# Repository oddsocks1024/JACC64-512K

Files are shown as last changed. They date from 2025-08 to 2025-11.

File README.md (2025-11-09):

# JACC64-512K
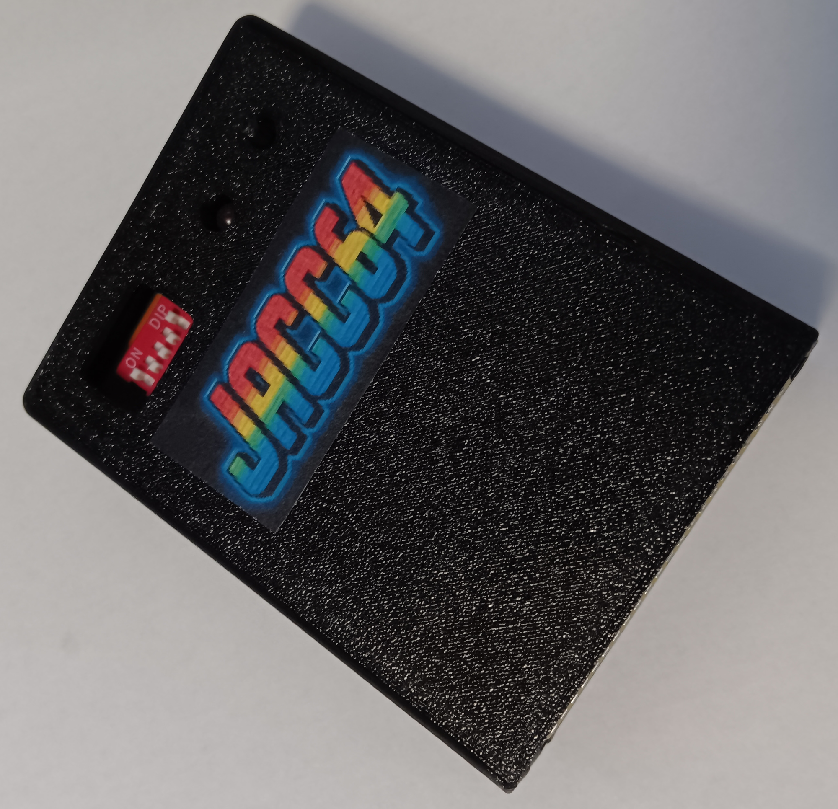
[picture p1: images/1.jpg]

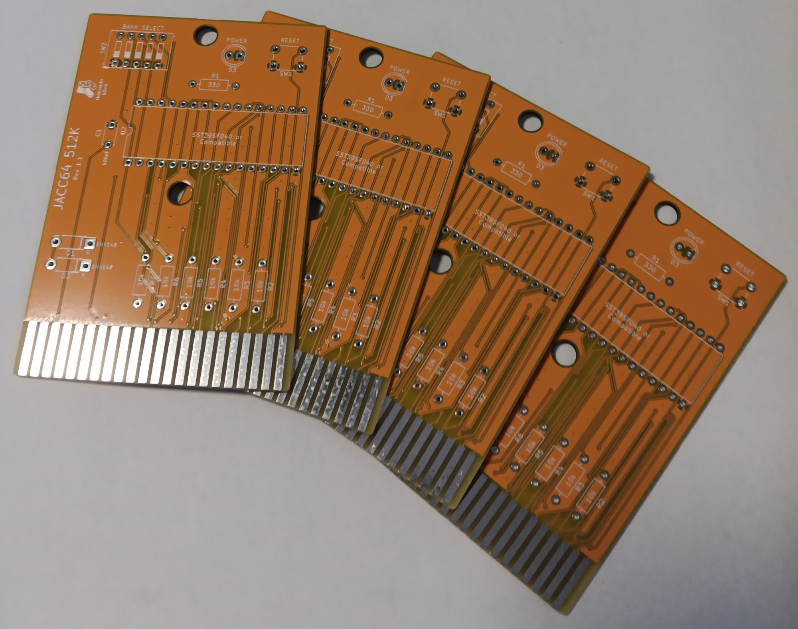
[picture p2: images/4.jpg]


## Description
JACC64-512K: Just Another Commodore Cartridge.

A cartridge for the Commodore 64 that holds 32 selectable 16K ROM images

**Additional Features**
* Power LED
* Reset Switch

## Bill of Materials

| Qty | Component |
|:---:|---|
| 1 | 5mm LED |
| 1 | 6mm Tactile Push Button |
| 1 | 330Ω Axial Resistor - ¼ watt (LED) |
| 6 | 10KΩ Axial Resistors - ¼ watt |
| 2 | 1N4148 Diodes |
| 1 | 100nF Ceramic Capacitor |
| 1 | 5-pole DIP Switch |
| 1 | SST39SF040 EEPROM (or compatible) |

* IC sockets optional
* The LED resistor is nominally 330Ω but anything up to 1K is fine
* You will need to join 32 x 16K ROM images together into a single image before burning to the EEPROM
* Smaller EEPROMs could be used, but will obviously hold fewer images and the DIP switch should be set accordingly

## 3D Printable Case
A 3D printable case specifically designed for this PCB is also available. STLs are included in this repo and there is also a [Thingiverse Page](https://www.thingiverse.com/thing:7089362)

* Designed to use screws as they produce a much nicer, more robust case
* 2 x 3.5mm self-tapping screws to attach the shells. Max length about 15mm

## Support Me
* [My Projects](https://projects.amiga-hardware.com) - Donate on this page
* [Order the JACC64-512K PCB](https://www.pcbway.com/project/shareproject/JACC64_512K_32_Game_C64_Cartridge_42f2de5b.html)
* [Order the JACC64-512K Case](https://www.pcbway.com/project/shareproject/JACC64_512K_C64_Cartridge_Case_49b9f140.html)

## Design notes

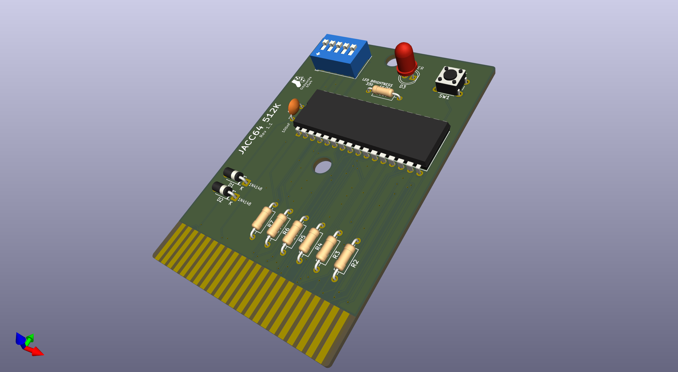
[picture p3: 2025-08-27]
images/JACC64-512K.png

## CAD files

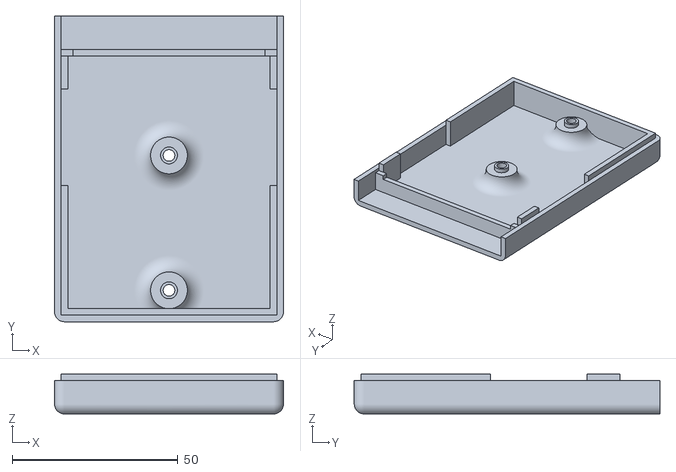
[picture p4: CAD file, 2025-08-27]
STL/JACC64-512K-Case-Bottom.stl
69.0 x 92.1 x 12.0

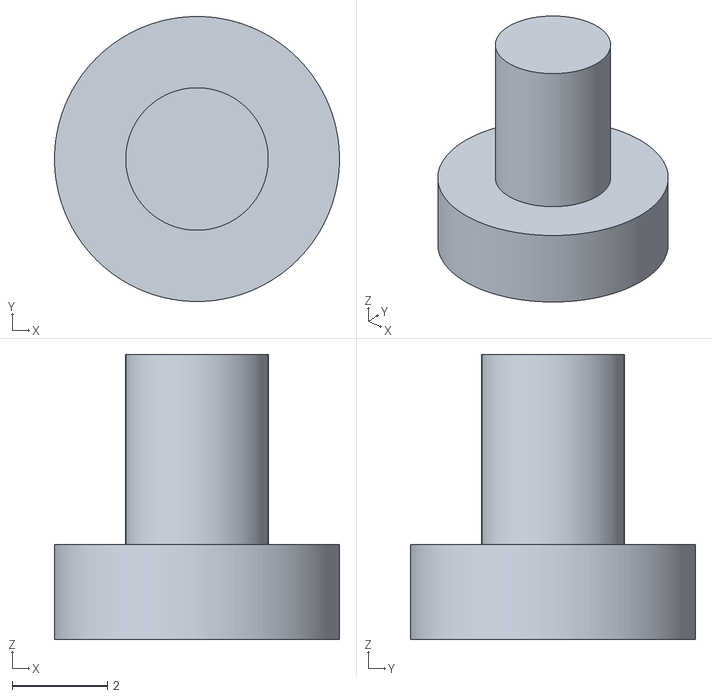
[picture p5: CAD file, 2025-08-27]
STL/JACC64-512K-Reset-Pin.stl
6.00 x 6.00 x 6.00

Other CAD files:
STL/JACC64-512K-Case-Top.stl

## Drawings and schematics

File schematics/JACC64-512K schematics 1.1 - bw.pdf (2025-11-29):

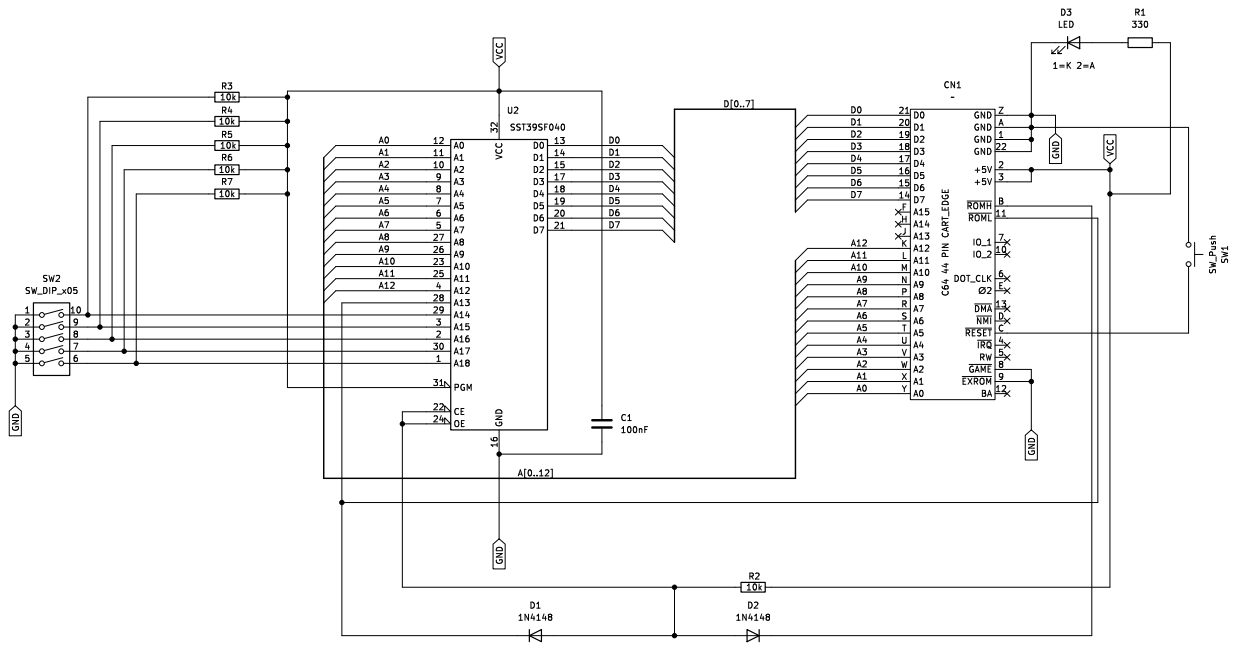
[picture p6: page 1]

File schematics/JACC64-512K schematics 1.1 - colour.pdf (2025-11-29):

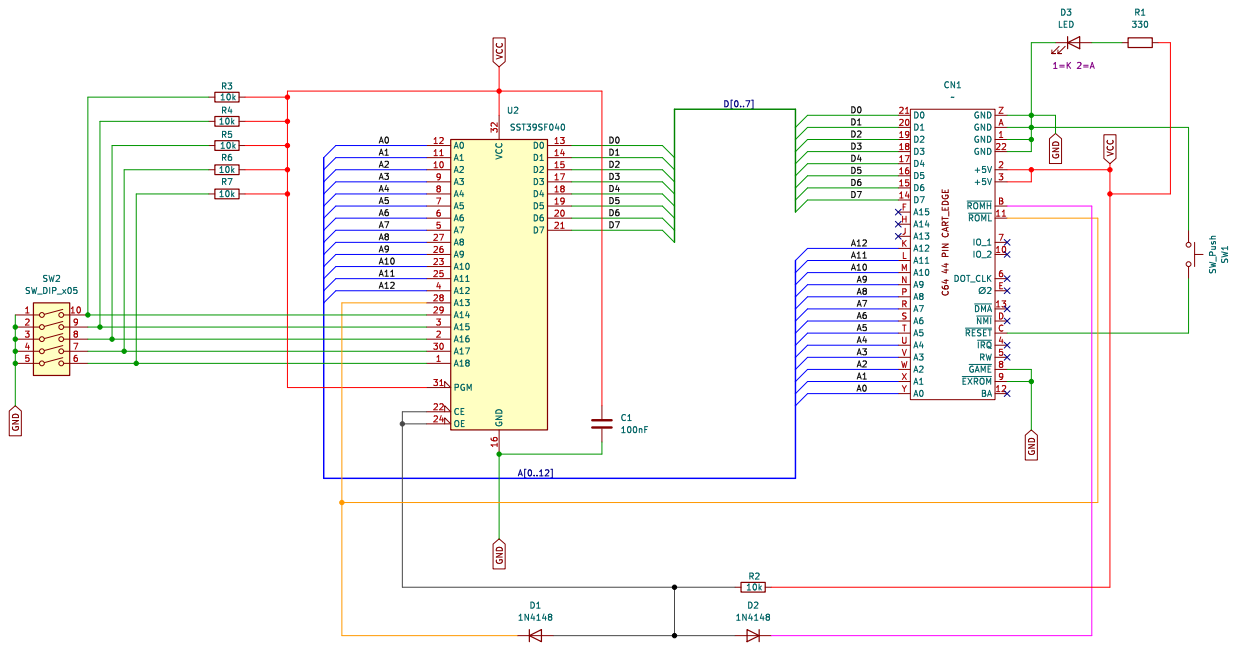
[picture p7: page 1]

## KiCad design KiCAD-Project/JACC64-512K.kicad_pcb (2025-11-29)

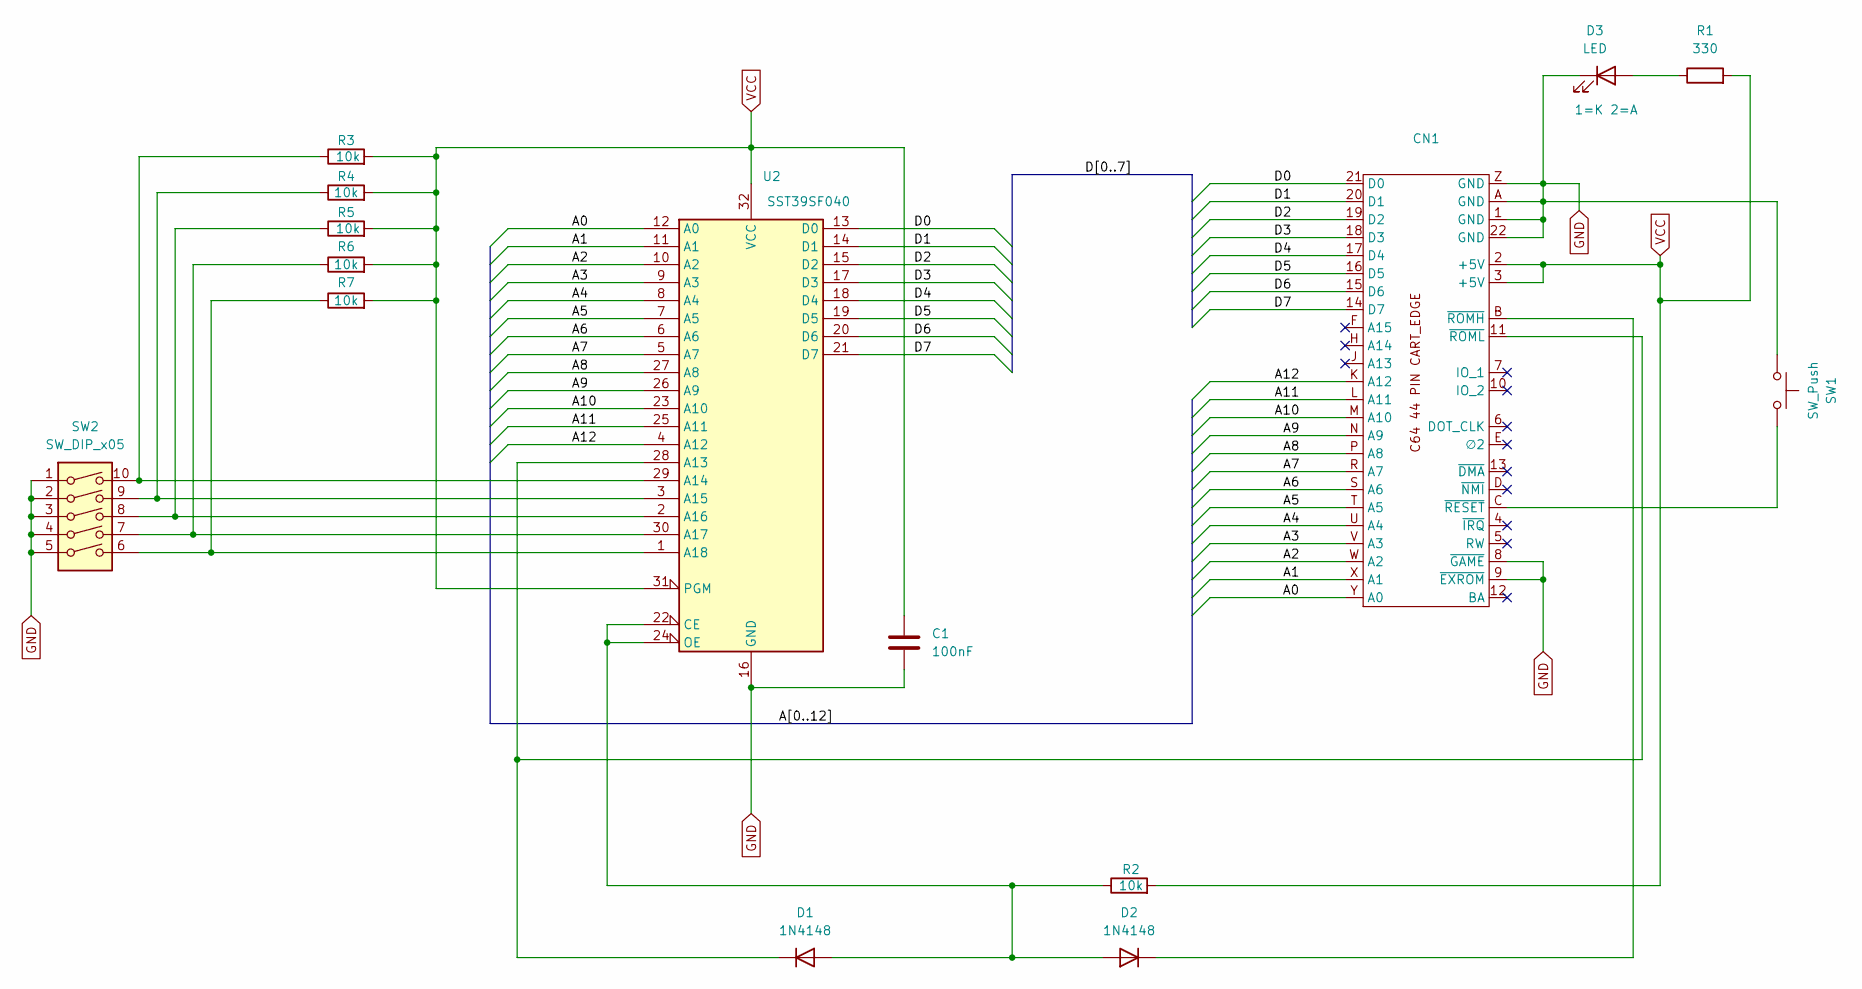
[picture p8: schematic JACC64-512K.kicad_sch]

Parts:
C1: 100nF; C_Disc_D5.0mm_W2.5mm_P5.00mm
CN1: C64 Expansion
D1, D2: 1N4148; D_DO-41_SOD81_P7.62mm_Horizontal
D3: LED; LED_D5.0mm
R1: 330; R_Axial_DIN0207_L6.3mm_D2.5mm_P10.16mm_Horizontal
R2, R3, R4, R5, R6, R7: 10k; R_Axial_DIN0207_L6.3mm_D2.5mm_P10.16mm_Horizontal
SW1: SW_Push; SW_PUSH_6mm
SW2: SW_DIP_x05; SW_DIP_SPSTx05_Slide_9.78x14.88mm_W7.62mm_P2.54mm
U2: SST39SF040; DIP-32_W15.24mm

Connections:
/A0: CN1.Y (A0), U2.12 (A0)
/A1: CN1.X (A1), U2.11 (A1)
/A2: CN1.W (A2), U2.10 (A2)
/A3: CN1.V (A3), U2.9 (A3)
/A4: CN1.U (A4), U2.8 (A4)
/A5: CN1.T (A5), U2.7 (A5)
/A6: CN1.S (A6), U2.6 (A6)
/A7: CN1.R (A7), U2.5 (A7)
/A8: CN1.P (A8), U2.27 (A8)
/A9: CN1.N (A9), U2.26 (A9)
/A10: CN1.M (A10), U2.23 (A10)
/A11: CN1.L (A11), U2.25 (A11)
/A12: CN1.K (A12), U2.4 (A12)
/D0: CN1.21 (D0), U2.13 (D0)
/D1: CN1.20 (D1), U2.14 (D1)
/D2: CN1.19 (D2), U2.15 (D2)
/D3: CN1.18 (D3), U2.17 (D3)
/D4: CN1.17 (D4), U2.18 (D4)
/D5: CN1.16 (D5), U2.19 (D5)
/D6: CN1.15 (D6), U2.20 (D6)
/D7: CN1.14 (D7), U2.21 (D7)
GND: C1.1, CN1.1 (GND), CN1.8 (~GAME), CN1.9 (~EXROM), CN1.22 (GND), CN1.A (GND), CN1.Z (GND), D3.1 (K), SW1.1, SW2.1, SW2.2, SW2.3, SW2.4, SW2.5, U2.16 (GND)
unnamed: CN1.C (~RESET), SW1.2
unnamed: CN1.B (~ROMH), D2.1 (K)
unnamed: CN1.11 (~ROML), D1.1 (K), U2.28 (A13)
unnamed: D1.2 (A), D2.2 (A), R2.1, U2.22 (CE), U2.24 (OE)
unnamed: D3.2 (A), R1.1
unnamed: R3.1, SW2.10, U2.29 (A14)
unnamed: R4.1, SW2.9, U2.3 (A15)
unnamed: R5.1, SW2.8, U2.2 (A16)
unnamed: R6.1, SW2.7, U2.30 (A17)
unnamed: R7.1, SW2.6, U2.1 (A18)
VCC: C1.2, CN1.2 (+5V), CN1.3 (+5V), R1.2, R2.2, R3.2, R4.2, R5.2, R6.2, R7.2, U2.31 (PGM), U2.32 (VCC)

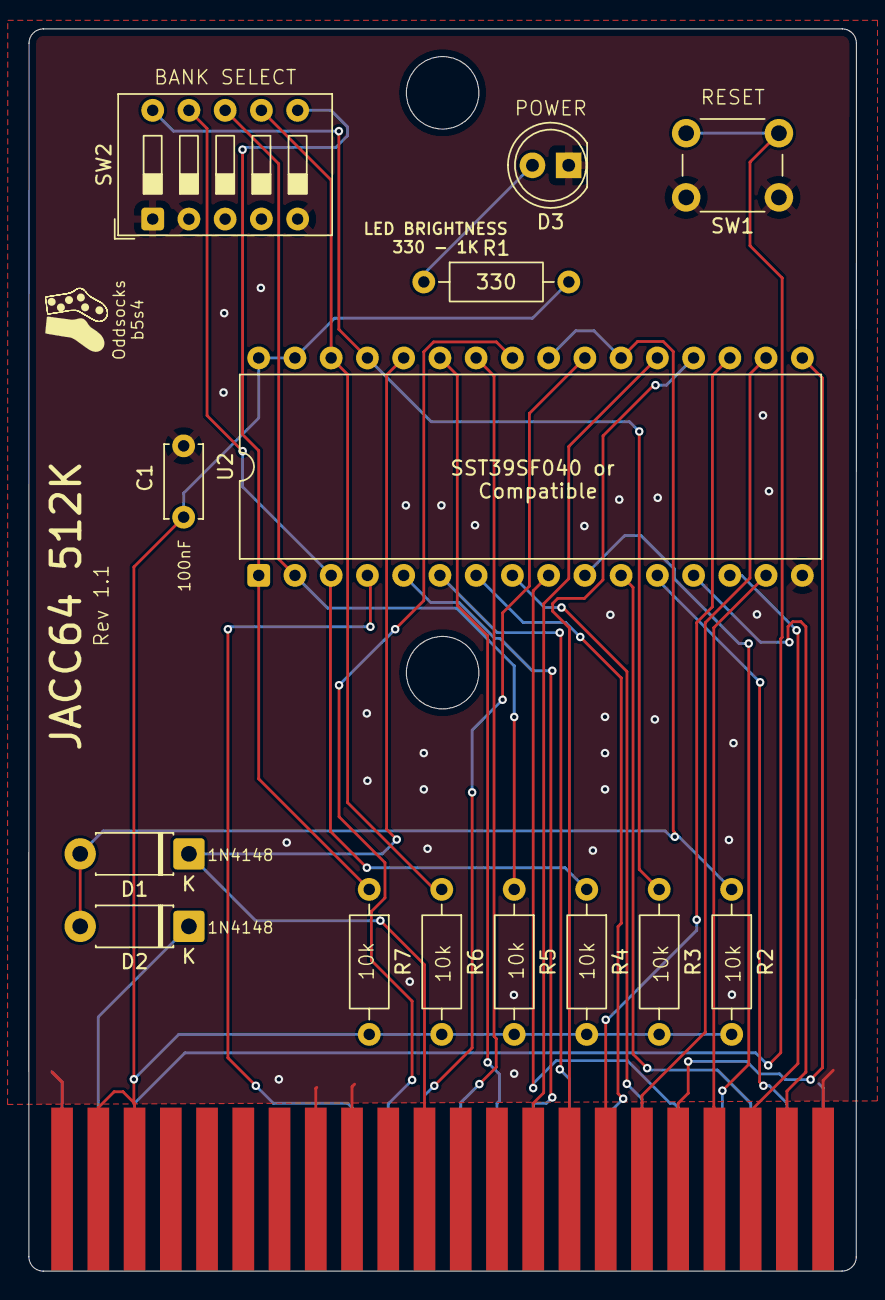
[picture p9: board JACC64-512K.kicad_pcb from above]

Board: 2 copper layers, 58.0 x 87.1 mm, 15 parts (0 on the bottom side), 33 nets.

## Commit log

2025-11-09 Added gerbers and updated README.md
    [JACC64-512K-B_Cu.gbl, JACC64-512K-B_Mask.gbs, JACC64-512K-B_Paste.gbp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]
2025-11-29 Added PDF schematics
    [JACC64-512K.kicad_pcb, JACC64-512K.kicad_sch]
